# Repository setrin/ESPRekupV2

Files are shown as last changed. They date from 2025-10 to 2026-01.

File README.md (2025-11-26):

# ESPRekup V2

**ESPRekup V2** — compact ESP32-C3 based controller boards designed specifically for the **Vent-Axia Sentinel Kinetic B**.  
Provides optocoupler switch emulation, RS232 diagnostics, wall-switch inputs and optional I²C sensors.

---

## Variants

### Full
- 3 optocouplers (SW1/SW2/SW3), 3 front buttons, wall impulse inputs, RS232 header, I²C.
- Visible user interface.
- <a href="ESPRekupV2-v32-Schematic.pdf">Schematic</a>

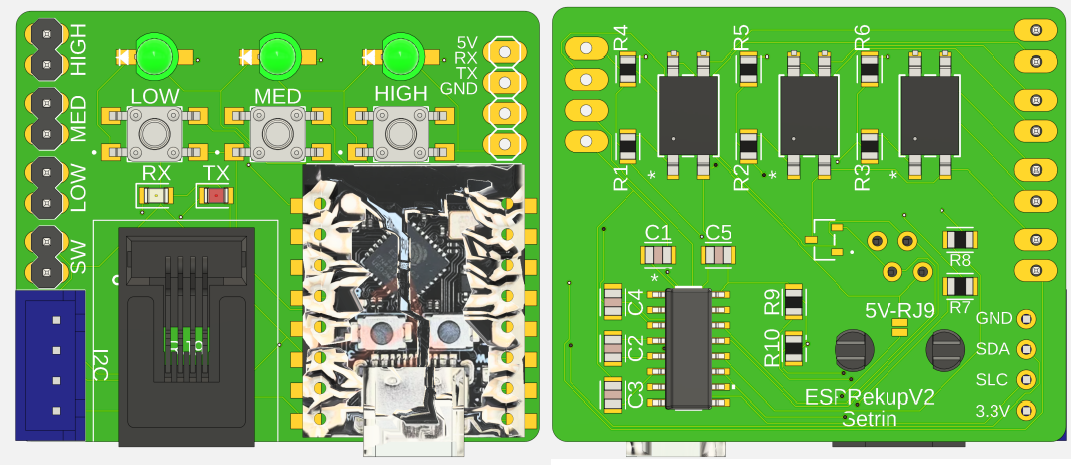
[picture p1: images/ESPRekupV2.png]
Full board


### Mini
- Same I/O as Full but **no front buttons** — intended for internal mounting inside the MVHR case.

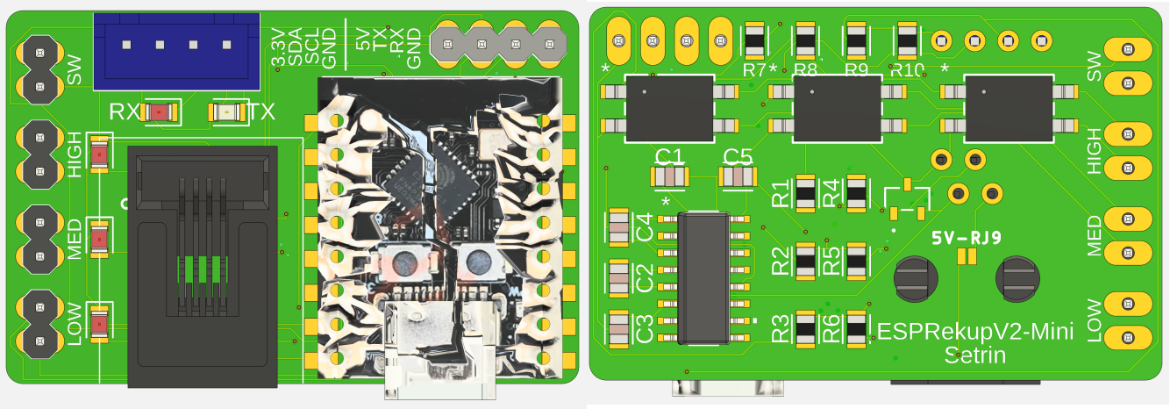
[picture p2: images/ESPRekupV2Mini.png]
Mini board


### Micro
- Minimal: RS232 + wall impulse inputs + I²C. Small footprint.

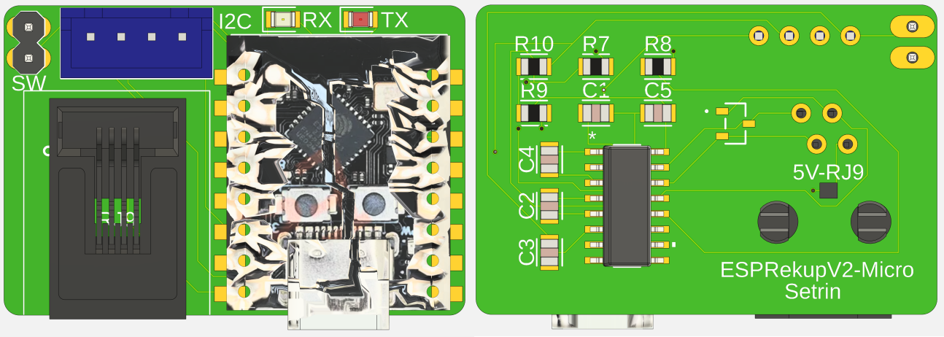
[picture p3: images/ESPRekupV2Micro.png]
Micro board


---

## Key points
- **Target device:** Vent-Axia Sentinel Kinetic B
- **Optocouplers** emulate the physical low/med/high switch closures expected by the Sentinel. This is the most compatible control method.  
- **RS232** is available for diagnostics and higher-level control if supported by your unit.

---

## Powering
- The board can be powered **either** from USB **or** from the MVHR via the RJ9 connector.  
- To select MVHR power, **bridge the power jumper on the back of the PCB** (check the silkscreen for the jumper label).  
> [!CAUTION]
> **Do NOT power from USB and RJ9 at the same time.** Removing one source before applying the other is mandatory to avoid damage.
---

## Software
- ESP32 is able to communicate with MVHR unit using forked version of alextrical's ESPHome component and read information shown on the unit's display
- All available information in diagnostics menu can be found [**here**](https://github.com/aelias-eu/vent-axia-remote/blob/main/docs/sentinel_kinetic-Diagnostic_Display.pdf)
- [Example ESPHome configs](https://github.com/setrin/ESPRekupV2/tree/master/esphome_configs)
---

## ESP32-C3 Pin-out
- GPIO0 -> Opto-coupuler Low mode
- GPIO1 -> Opto-coupuler Medium / Normal mode
- GPIO2 -> NC
- GPIO3 -> Opto-coupuler High / Boost mode
- GPIO4 -> NC
- GPIO5 -> Button Low mode
- GPIO6 -> Button Medium / Normal mode
- GPIO7 -> Button High / Boost mode
- GPIO8 -> I2C SDA
- GPIO9 -> I2C SCL
- GPIO10 -> Grounded Input for Impulse wall switches
- GPIO20 -> RX
- GPIO21 -> TX
---

## References

- @Alextrical PCB Design inspiration [ESP32-Sentinel-Kinetic-Wireless-Dongle](https://github.com/alextrical/ESP32-Sentinel-Kinetic-Wireless-Dongle)
- @Alextrical ESPHome Component [ESPHome-Vent-Axia-Sentinel-Kinetic](https://github.com/alextrical/ESPHome-Vent-Axia-Sentinel-Kinetic/)
- @aelias-eu Vent-Axia wired remote protocol reverse engineering [vent-axia-remote](https://github.com/aelias-eu/vent-axia-remote)

---

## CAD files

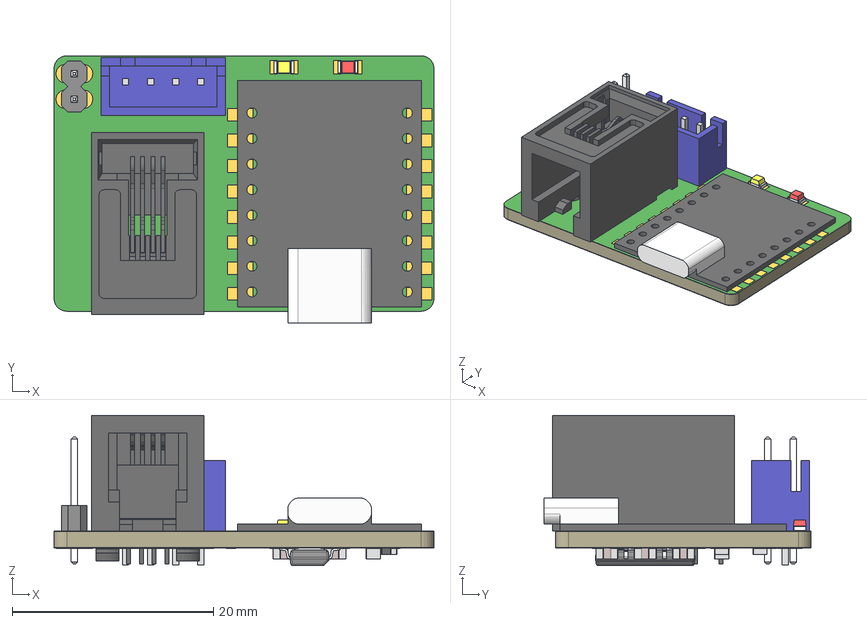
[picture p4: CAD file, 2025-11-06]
steps/ESPRekupV2Micro-v7.step
37.8 x 26.6 x 15.0 mm
Board
1-copper
64-copper
1-soldermask
64-soldermask
95501-2441 v1
CAPC2012X110 x 5
B4B-XH-A v1
ESP32-C3-SUPERMINI-3DMODEL v7
BODY-SO
LEAD-SO x 16
5576561.f3d x 4
42899.f3d

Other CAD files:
f3ds/ESPRekupV2Micro-v7.f3d
f3ds/ESPRekupV2Mini-v22.f3d

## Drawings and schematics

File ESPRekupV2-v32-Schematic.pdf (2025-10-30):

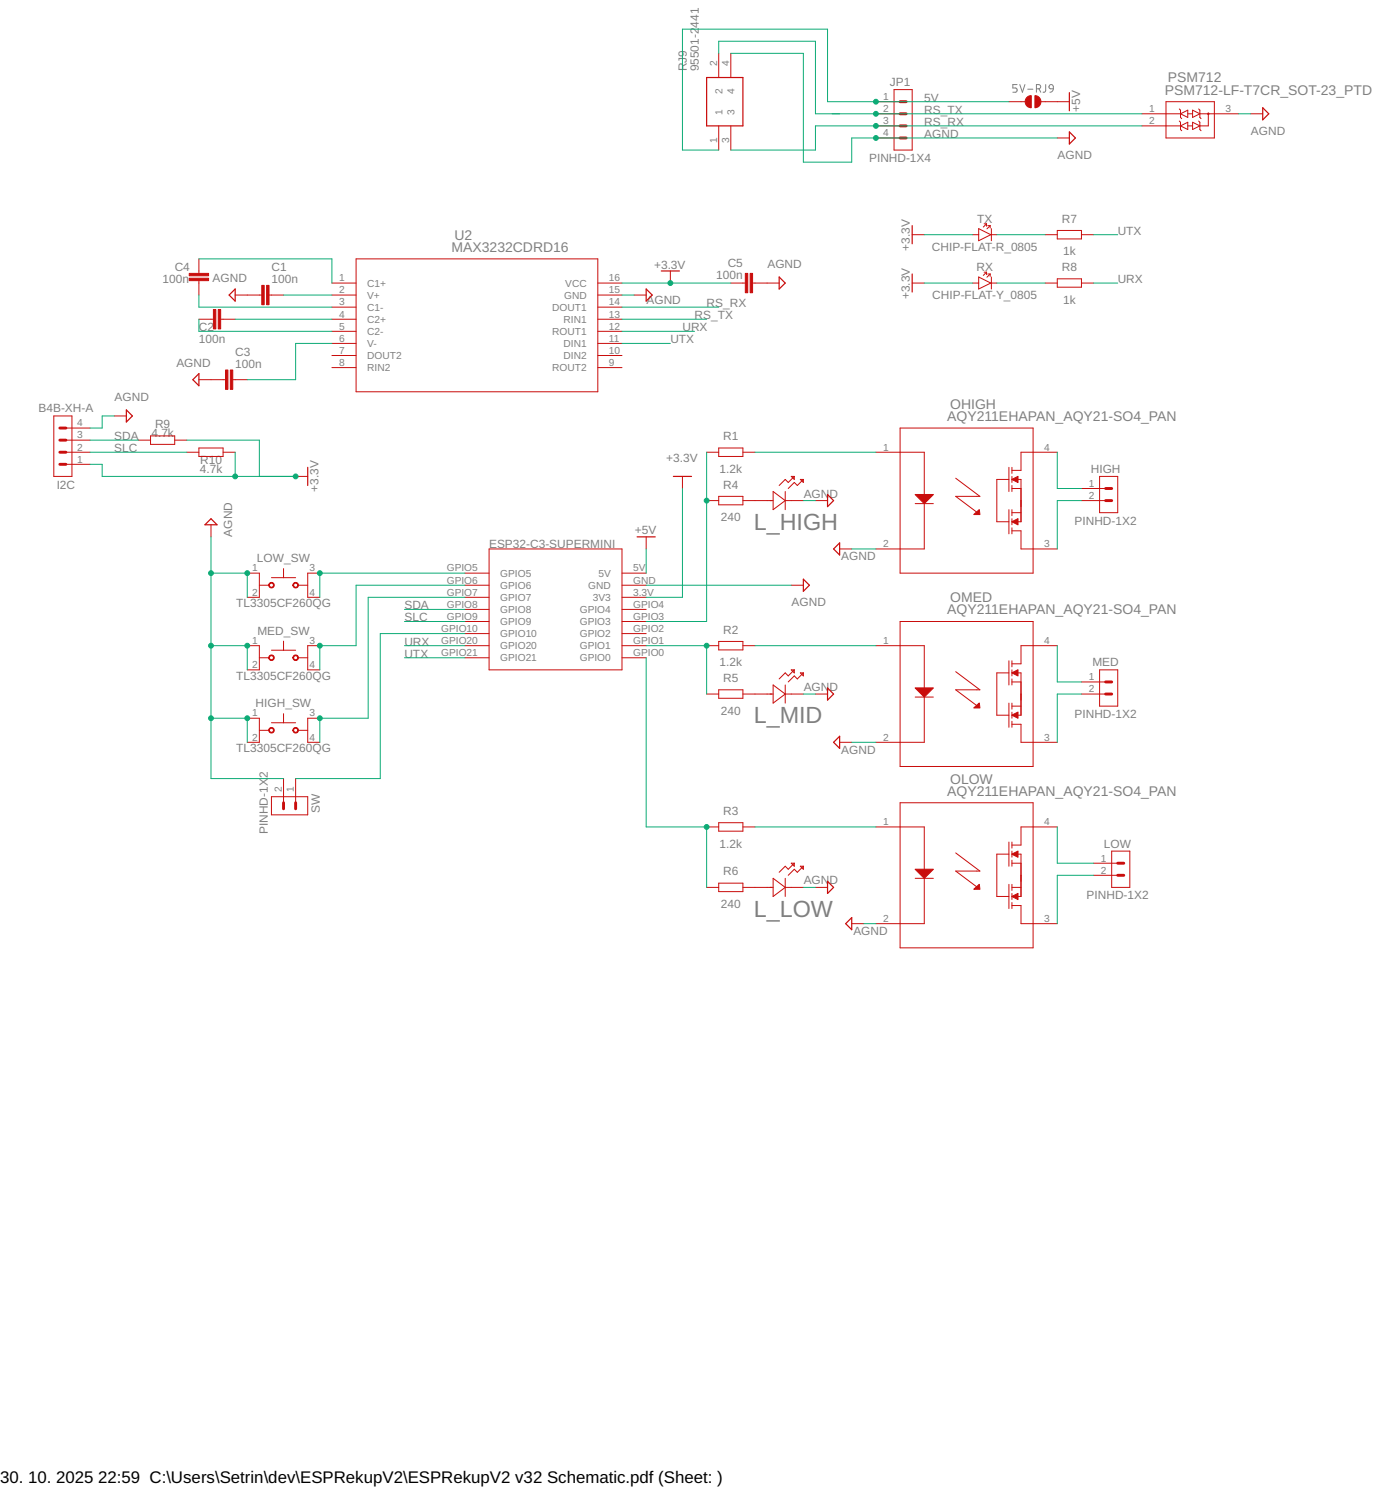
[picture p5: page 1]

30. 10. 2025 22:59 C:\Users\Setrin\dev\ESPRekupV2\ESPRekupV2 v32 Schematic.pdf (Sheet: )

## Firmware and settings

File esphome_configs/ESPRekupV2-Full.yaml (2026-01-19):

#TODO: Fix Diagnostic length useage
substitutions:
  name: "esprecup-v2-full"
  friendly_name: "ESPRecupV2-Full"
  diagnostic: "Diagnostic" # Diagnostic line
  manual: "Manual" # MVHR Line 2 when mode is set manually
  auto_mode: "Auto" # MVHR Line 2 when mode is set automatically (default or unit's schedule)
  low_mode: "Low"  # MVHR Line 1 Low Mode
  normal_mode: "Normal" # MVHR Line 1 Normal Mode
  boost_mode: "Boost" # MVHR Line 1 Boost Mode
  boost_mode_timer: "Boost - Timer" # MVHR Line 1 + Timer
  log_level: DEBUG

esphome:
  name: ${name}
  friendly_name: ${friendly_name}

esp32:
  board: esp32-c3-devkitm-1
  framework:
    type: esp-idf

# Enable logging
logger:
  level: ${log_level}

api:

ota:
  - platform: esphome
    id: ota_esphome

wifi:

improv_serial:

esp32_improv:
  authorizer: none

captive_portal:

uart:
  tx_pin: 21
  rx_pin: 20
  baud_rate: 9600
  id: vask_uart

i2c:
  sda: GPIO8
  scl: GPIO9
  scan: false
  id: i2c_bus

external_components:
  - source: github://setrin/ESPHome-Vent-Axia-Sentinel-Kinetic/@latest

globals:
  - id: prev_mode
    type: std::string
    restore_value: false
  - id: boost_timer_active
    type: bool
    restore_value: false

vent_axia_sentinel_kinetic:
  - id: vask
    uart_id: vask_uart
    line1:
      id: line_1
      name: "Line 1"
      icon: "mdi:text-short"
      on_value:
        then:
          - lambda: |-
              if (x.rfind("${low_mode}", 0) == 0) {
                id(current_mode).publish_state("Low");
              } else if (x.rfind("${normal_mode}", 0) == 0) {
                id(current_mode).publish_state("Normal");
              } else if (x.rfind("${boost_mode}", 0) == 0){
                id(current_mode).publish_state("Boost");
              } else {
                id(current_mode).publish_state("N/A");
              }
    line2:
      id: line_2
      name: "Line 2"
      icon: "mdi:text-short"
      on_value:
        then:
          - lambda: |-
              if (id(line_1).state.find("${diagnostic}", 0) == 0) {
                  switch (std::stoi(id(line_1).state.substr(12, 2))) {
                      case 0:
                          id(supply_fan_speed).publish_state(std::stoi(x.substr(0, 3)));
                          id(supply_pwm).publish_state(std::stoi(x.substr(4, 3)));
                          id(supply_rpm).publish_state(std::stoi(x.substr(10, 4)));
                          break;
                      case 1:
                          id(extract_fan_speed).publish_state(std::stoi(x.substr(0, 3)));
                          id(extract_pwm).publish_state(std::stoi(x.substr(4, 3)));
                          id(extract_rpm).publish_state(std::stoi(x.substr(10, 4)));
                          break;
                      case 2:
                          id(supply_temp_sensor).publish_state(std::stoi(x.substr(1, 2)));
                          break;
                      case 3:
                          id(extract_temp_sensor).publish_state(std::stoi(x.substr(1, 2)));                          
                          break;
                      case 23:
                          id(filter_hours_remain).publish_state(std::stoi(x.substr(0, 5)));                        
                          break;
                      default:
                          // Handle other cases
                          break;
                  }
              }
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

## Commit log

2025-11-06 Clean up and adding step files
    [ESPRekupV2Micro-v7.f3d, ESPRekupV2Micro-v7.step, ESPRekupV2Mini-v22.f3d]
2025-12-12 Fixed package import URL for esphome confis
    [ESPRekupV2-Full.yaml, ESPRekupV2-Mini.yaml]
